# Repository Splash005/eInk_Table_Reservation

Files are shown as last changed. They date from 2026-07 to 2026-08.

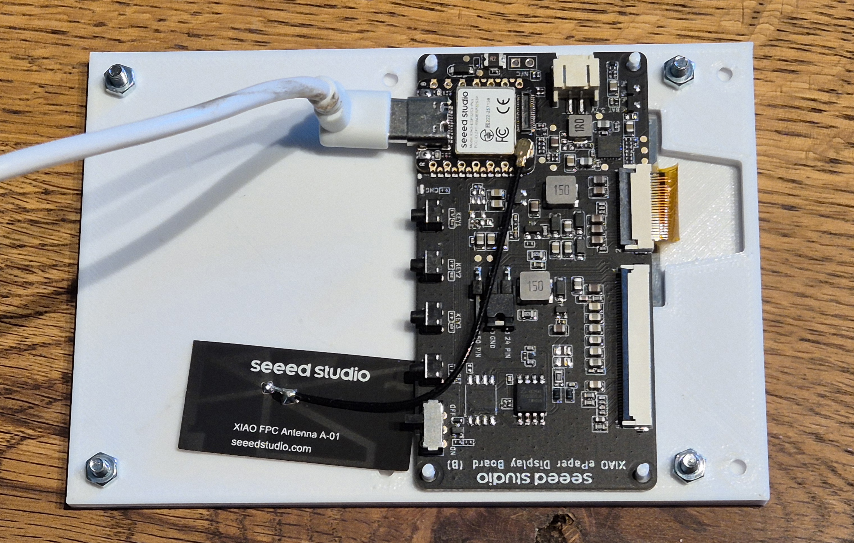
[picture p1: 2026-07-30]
pictures/Backside_with_PCB.jpg

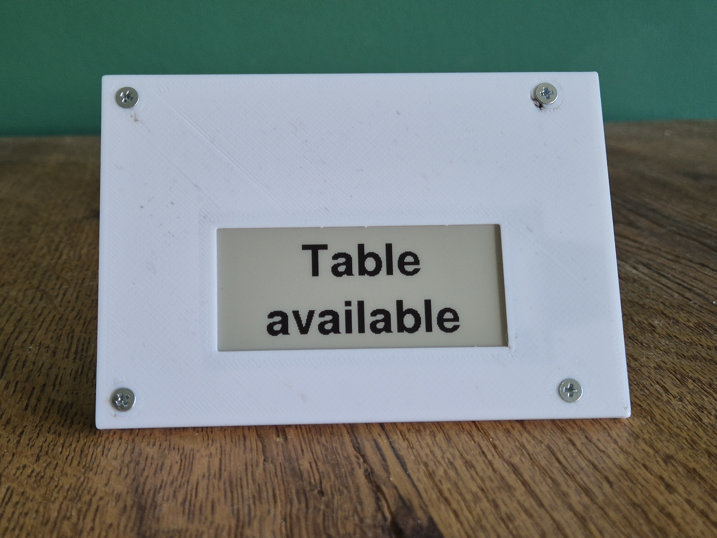
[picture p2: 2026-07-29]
pictures/Display_State_AVAILABLE.jpg

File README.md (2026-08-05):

# eInk_Table_Reservation
A Demo-Project for a smart Table-Reservation Sign, which has an integrated Webserver and handles reservations.  
It periodically checks the time and when the reservation is upcoming the screen changes to show customers that the table is reserved. When the reservation starts, it changes again its screen to welcome the customer and display a QR code with a link to the menu card.
The Wifi can be reconfigured over a webportal or reset with a physical button at the back of the board.
  
It is based on an ESP32 S3 and a 2,9 inch 4-color eInk Display. The driver board can be battery powered, but the software is currently designed to run on USB.

Video of the project:
https://youtu.be/43O6_xG3Szs

### Following products have been used:
- Driver Board --> XIAO ePaper Display Board(ESP32-S3) - EE04 (SKU 100075670)
- eInk Display --> 2.9" Quadruple Color eInk / ePaper Display with 128x296 Pixels, SPI interface, Support XIAO/Arduino (SKU 104990855)

| component | spezification / type |
| --- | --- |
| Microcontroller | ESeeed Studio XIAO ESP32S3 PLUS |
| Display | 2.9" E-Ink, 4-color (GDEY029F52) |
| Display-driver IC | JD79661 (resolution: 296 x 128 Pixel) |

## Used external libaries:
- **GxEPD2_4C** - for contolling the eInk display (custom integration designed from me for the above mentioned screen)
- **WiFiManager** - for the capitave Portal to configure the Wifi
- **QRCode** - custom integration for the generation of QR codes directly on the ESP
- **Standard ESP Libaries** - WiFi.h, WebServer.h, Preferences.h, time.h
  
## Pin wiring
| Function | ESP32 Pin | Description |
| --- | --- | --- |
| EPD_CS | D7 | Chip Select (SPI) |
| EPD_DC | 10 | Data/Command Control |
| EPD_RST | 38 | Reset Pin |
| EPD_BUSY | D3 | Busy-Signal of the display|
| SPI_SCK | D8 | SPI Clock |
| SPI_MOSI | D10 |SPI Master Out Slave In |
| SPI_MISO | 8 | SPI Master In Slave Out |
  
## State machine and display logic
| state | condition | display |
| --- | --- | --- |
| STATE_AVAILABLE | > 60 Min. before the starttime OR after endtime | big centered text: "Table available". |
| STATE_UPCOMING | less or exactly 60 minutes before the start time | yellow Warning background on the top. Text: "This table is reserved! From [Start] till [End] for: [Name]". Name in red. |
| STATE_ACTIVE | current time is between start and end time | "Welcome [Name]" (Name in red). QR-Code to the menu card. Endtime with yellow Font and outlined with black. |
  
## Logic Diagram
```
======================================================================
                         [ SETUP FUNCTION (setup) ]
======================================================================
                                   |
                                   v
             [ Init: Hardware, Display & load saved data ]
                                   |
                                   v
         +---------------- ( WiFi known? ) ------------------+
         |                                                   |
      [ Yes ]                                              [ No ]
         |                                                   |
         |                                                   v
         |                                [ start AP-Mode (Table_Reservation_AP) ]
         |                                [ display shows IP & QR-Code           ]
         |                                                   |
         |<--------------------------------------------------+ (After the setup from web portal)
         v
 [ get time (NTP)  ]
         |
 [ start webserver ]
         |
         v
======================================================================
                        [ MAIN FUNCTION (loop) ]
======================================================================
         |
         +
         |                                                       
         v                                                        
[ Check Web interfaces ] --> (New Data?) -> [ save and force Update]
         |                                                       
         v                                                       
[ Check Button ] ------> (3 Sec. pressed?) -> [ reset WiFi & Restart ]
         |                                                      
         v                                                       
( 10 seconds elapsed OR forced screen update? ) ------[ No ] -----+           
         |                                                        |
       [ Yes ]                                                    |
         |                                                        |
         v                                                        |
[ check time & State (updateDisplayLogik) ]                       |
         |                                                        |
         +---> (time < starttime AND > 60 Min) ---> [ AVAILABLE ] |
         +---> (time < starttime AND <= 60 Min) --> [ UPCOMING ]  |
         +---> (time >= starttime AND < endtime) -> [ ACTIVE ]    |
         +---> (time >= endtime) -----------------> [ AVAILABLE ] |
         |                                                        |
         v                                                        |
( state changed or display update is forced? ) -------[ No ] -----+  
         |                                                        |
       [ Yes ]                                                    |
         |                                                        |
         v                                                        |
[ update eInk display ]                                           |
         |                                                        |
[ set eInk in Hibernate mode ]                                    |
         |                                                        |
         +--------------------------------------------------------+
```
  
## Known Issues:
- currently the reservation is not deleted after it elapsed therefor it is still in memory and the table will be reserved the next day again.
  - Solution: After endtime elapsed delete reservation or create a flag if reservation has elapsed and check in the program for the flag. 

## Future Improvements:
- add an array of reservations and the ESP checks itself which reservation is next and after it elapsed delete it from the array
  - Advantages:
    - Multiple reservations can be entered for one table
        
- change the architecture from a webserver to a client which connects to a server and checks if reservations are available for this table (one server --> multiple Client architecture). The Reservation handling is done on the server and the client just checks it status and updates the display then goes to low power sleep.
  - Advantages:
    - Reservation handling is done on the server side (all reservations can be entered in one place with an table number and the clients check automatically if there is an upcoming reservation for their table number)
    - Client can be battery powered and goes to deepsleep until next check (currently no deepsleep for the ESP because it runs the webserver, the eink display is in sleep)

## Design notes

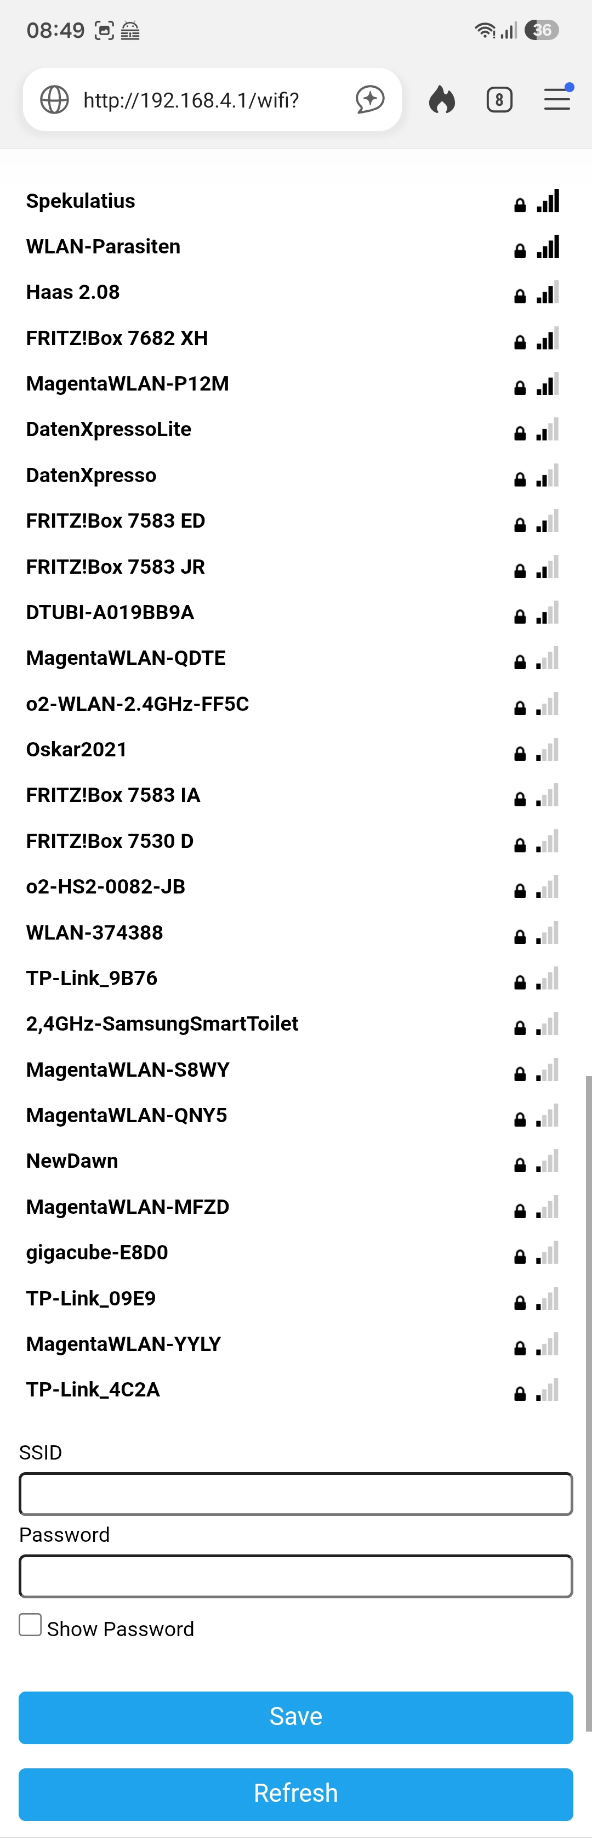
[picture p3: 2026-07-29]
pictures/Configure_WIFI_2.jpg

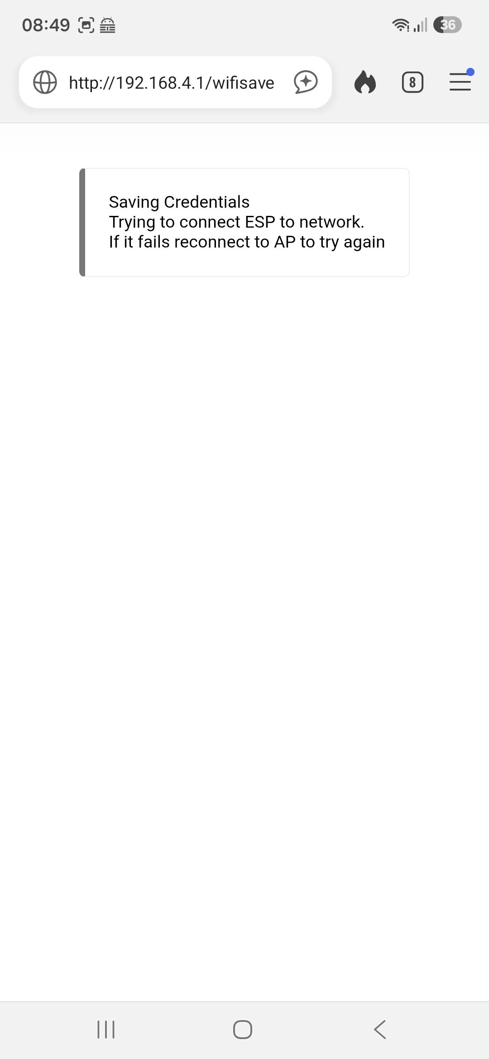
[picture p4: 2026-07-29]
pictures/Configure_WIFI_3.jpg

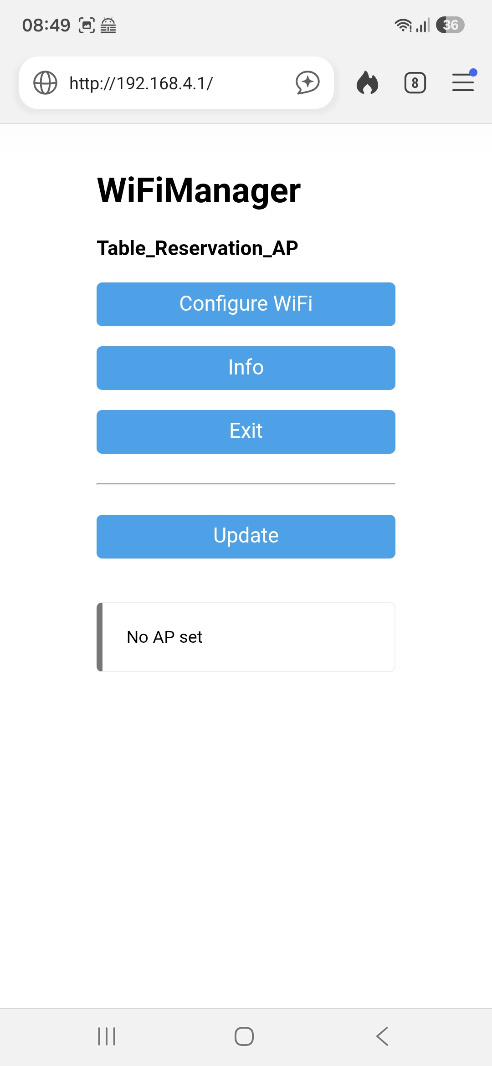
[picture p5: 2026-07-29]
pictures/Configure_WIFI_1.jpg

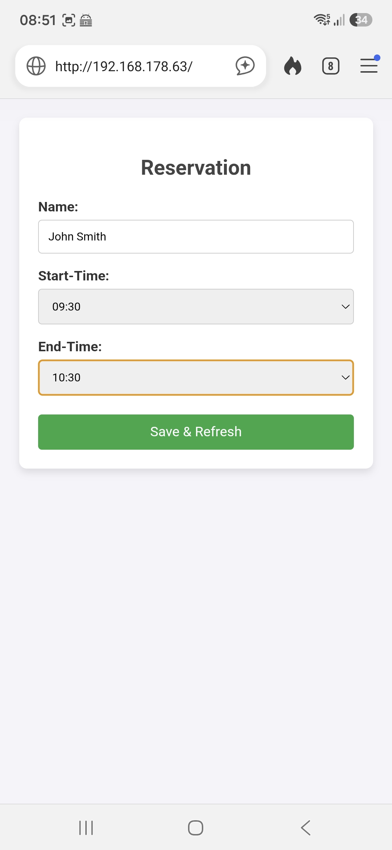
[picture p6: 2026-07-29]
pictures/Reservation_Website.jpg

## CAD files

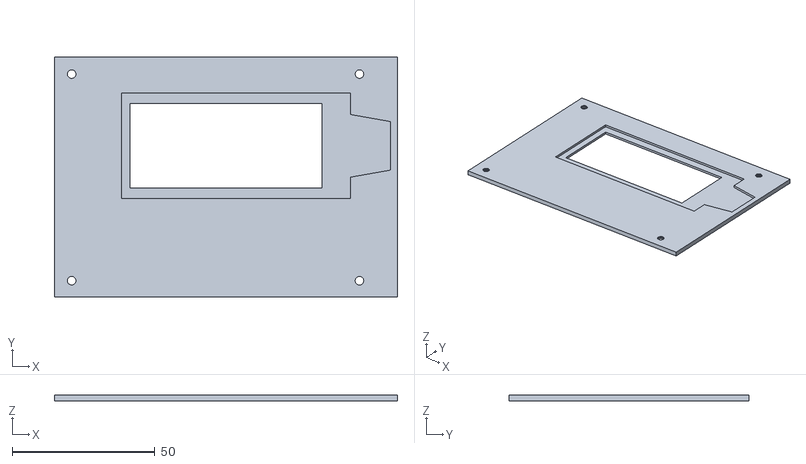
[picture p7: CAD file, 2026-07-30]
enclosure/Display_Holder.stl
120.0 x 84.0 x 2.00

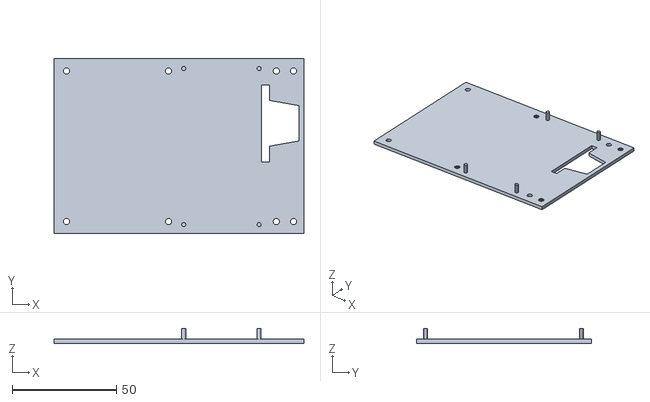
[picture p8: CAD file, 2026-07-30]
enclosure/BreakoutBoard_Holder.stl
120.0 x 84.0 x 7.00

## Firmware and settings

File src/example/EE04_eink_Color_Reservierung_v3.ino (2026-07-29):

/*
======================================================================
Interactive Table reservation Sign
======================================================================

This interactive table reservation sign should show the features of
an colored eink display. It is dynamically adjusting its content to
the time and status of the table.
The backend is currently a simple webserver where a name, start and
endtime can be configured, but in the future it can be modified to
be able to recieve data over mqtt or any other server-client connection.

This project was made for the "make a sign" competition of SeeedStudio.

Created by: S. Perrevoort
Date of last modification: 29.07.2026


********** Logic Diagram **********


======================================================================
                         [ SETUP FUNCTION (setup) ]
======================================================================
                                   |
                                   v
             [ Init: Hardware, Display & load saved data ]
                                   |
                                   v
         +---------------- ( WiFi known? ) ------------------+
         |                                                   |
      [ Yes ]                                              [ No ]
         |                                                   |
         |                                                   v
         |                                [ start AP-Mode (Table_Reservation_AP) ]
         |                                [ display shows IP & QR-Code           ]
         |                                                   |
         |<--------------------------------------------------+ (After the setup from web portal)
         v
 [ get time (NTP)  ]
         |
 [ start webserver ]
         |
         v
======================================================================
                        [ MAIN FUNCTION (loop) ]
======================================================================
         |
         +
         |                                                       
         v                                                        
[ Check Web interfaces ] --> (New Data?) -> [ save and force Update]
         |                                                       
         v                                                       
[ Check Button ] ------> (3 Sec. pressed?) -> [ reset WiFi & Restart ]
         |                                                      
         v                                                       
( 10 seconds elapsed OR forced screen update? ) ------[ No ] -----+           
         |                                                        |
       [ Yes ]                                                    |
         |                                                        |
         v                                                        |
[ check time & State (updateDisplayLogik) ]                       |
         |                                                        |
         +---> (time < starttime AND > 60 Min) ---> [ AVAILABLE ] |
         +---> (time < starttime AND <= 60 Min) --> [ UPCOMING ]  |
         +---> (time >= starttime AND < endtime) -> [ ACTIVE ]    |
         +---> (time >= endtime) -----------------> [ AVAILABLE ] |
         |                                                        |
         v                                                        |
( state changed or display update is forced? ) -------[ No ] -----+  
         |                                                        |
       [ Yes ]                                                    |
         |                                                        |
         v                                                        |
[ update eInk display ]                                           |
         |                                                        |
[ set eInk in Hibernate mode ]                                    |
         |                                                        |
         +--------------------------------------------------------+
*/

#include <WiFi.h>
#include <WiFiManager.h>
#include <WebServer.h>
#include <Preferences.h>
#include <time.h>
#include <qrcode_gen.h>

// --- E-Ink Display Setup (GxEPD2) ---
// JD79661 - GDEY029F52
// 296 width x 128 height

#include <GxEPD2_4C.h>
#include <Fonts/FreeSans9pt7b.h>
#include <Fonts/FreeSansBold9pt7b.h> // bold
#include <Fonts/FreeSans12pt7b.h>
#include <Fonts/FreeSansBold12pt7b.h> // bold
#include <Fonts/FreeSans18pt7b.h>
#include <Fonts/FreeSansBold18pt7b.h> // bold
#include <Fonts/FreeSans24pt7b.h>
#include <Fonts/FreeSansBold24pt7b.h> // bold

#define MAX_DISPLAY_BUFFER_SIZE 65536ul 
#define MAX_HEIGHT(EPD) (EPD::HEIGHT <= MAX_DISPLAY_BUFFER_SIZE / (EPD::WIDTH / 8) ? EPD::HEIGHT : MAX_DISPLAY_BUFFER_SIZE / (EPD::WIDTH / 8))

// Configuration Constants
const char* WIFI_AP_NAME = "Table_Reservation_AP";

// SPI Pins für ESP32-S3 (HSPI)
const int EPD_CS = D7;  
const int EPD_DC = 10;  
const int EPD_RST = 38;  
const int EPD_BUSY = D3;  
const int SPI_SCK = D8;  
const int SPI_MOSI = D10; 
const int SPI_MISO = 8;  

GxEPD2_4C<GxEPD2_290c_GDEY029F52, MAX_HEIGHT(GxEPD2_290c_GDEY029F52)> display(GxEPD2_290c_GDEY029F52(/*CS=*/ EPD_CS, /*DC=*/ EPD_DC, /*RST=*/ EPD_RST, /*BUSY=*/ EPD_BUSY));

// --- Pushbutton Pins ---
const int BTN_WAKE_1 = 2; // to be defined
const int BTN_WAKE_2 = 3; // to be defined
const int BTN_CONFIG = 5; // reset WiFi

// --- Webserver ---
WebServer server(80);

// --- variables & memory ---
Preferences preferences;
String resName = "John Doe";
String startTime = "18:00";
String endTime = "20:00";

const char* ntpServer = "pool.ntp.org";
const char* tzInfo = "CET-1CEST,M3.5.0,M10.5.0/3"; 

// --- state machine for the display ---
enum DisplayState { STATE_UNKNOWN, STATE_AVAILABLE, STATE_UPCOMING, STATE_ACTIVE };
DisplayState currentDisplayState = STATE_UNKNOWN;
bool forceDisplayUpdate = true; // force update at the beginning

unsigned long lastTimeCheck = 0;
const unsigned long timeCheckInterval = 10000; // check every 10 seconds

// --- HELPER functions ---
int getMinutesFromMidnight(String timeStr) {
  int h, m;
  if (sscanf(timeStr.c_str(), "%d:%d", &h, &m) == 2) {
    return h * 60 + m;
  }
  return 0;
}

void drawCenteredText(const String& text, int yPos) {
  // 1. variables for the textrecognition
  int16_t tbx, tby;
  uint16_t tbw, tbh;

  // 2. Calculate Textboundaries
  display.getTextBounds(text, 0, 0, &tbx, &tby, &tbw, &tbh);

  // 3. calculate X-coordinate for the middle of the screen
  int centerX = (display.width() - tbw) / 2 - tbx;

  // 4. draw text
  display.setCursor(centerX, yPos);
  display.print(text);
}

void drawOutlinedText(String text, int x, int y, uint16_t fillingcolor) {
  // 1. Draw BLACK text with an offset
  display.setTextColor(GxEPD_BLACK);
  
  display.setCursor(x - 1, y); display.print(text);
  display.setCursor(x + 1, y); display.print(text);
  display.setCursor(x, y - 1); display.print(text); 
  display.setCursor(x, y + 1); display.print(text);
  
  // Optional: diagonal offset for a smoother transition
  display.setCursor(x - 1, y - 1); display.print(text);
  display.setCursor(x + 1, y - 1); display.print(text);
  display.setCursor(x - 1, y + 1); display.print(text);
  display.setCursor(x + 1, y + 1); display.print(text);

  // 2. Fill in the Text in the middle in the defined color
  display.setTextColor(fillingcolor);
  display.setCursor(x, y);
  display.print(text);
}

void drawQRCode(const char* url, int offsetX, int offsetY, int scale) {
  QRCode qrcode;
  uint8_t qrcodeData[qrcode_getBufferSize(3)];
  qrcode_initText(&qrcode, qrcodeData, 3, 0, url);

  for (uint8_t y = 0; y < qrcode.size; y++) {
    for (uint8_t x = 0; x < qrcode.size; x++) {
      if (qrcode_getModule(&qrcode, x, y)) {
        display.fillRect(offsetX + (x * scale), offsetY + (y * scale), scale, scale, GxEPD_BLACK);
      }
    }
  }
}

// --- HTML for the webinterface ---
const char* htmlForm = R"rawliteral(
<!DOCTYPE html>
<html>
<head>
  <meta charset="UTF-8">
  <meta name="viewport" content="width=device-width, initial-scale=1.0">
  <title>Table-Reservation</title>
  <style>
    body { font-family: Arial, sans-serif; margin: 20px; background-color: #f4f4f9; color: #333; }
    .container { max-width: 400px; margin: auto; background: white; padding: 20px; border-radius: 8px; box-shadow: 0 4px 8px rgba(0,0,0,0.1); }
    h2 { text-align: center; color: #444; }
    label { font-weight: bold; display: block; margin-top: 15px; }
    input[type="text"], input[type="time"] { width: 100%; padding: 10px; margin-top: 5px; border: 1px solid #ccc; border-radius: 4px; box-sizing: border-box; }
    input[type="submit"] { width: 100%; padding: 10px; margin-top: 20px; background-color: #28a745; color: white; border: none; border-radius: 4px; cursor: pointer; font-size: 16px; }
    input[type="submit"]:hover { background-color: #218838; }
  </style>
</head>
<body>
  <div class="container">
    <h2>Reservation</h2>
    <form action="/save" method="POST">
      <label>Name:</label>
      <input type="text" name="name" value="%NAME%" maxlength="40" required>
      <label>Start-Time:</label>
      <input type="time" name="start" value="%START%" required>
      <label>End-Time:</label>
      <input type="time" name="end" value="%END%" required>
      <input type="submit" value="Save & Refresh">
    </form>
  </div>
</body>
</html>
)rawliteral";

void handleRoot() {
  String page = htmlForm;
  page.replace("%NAME%", resName);
  page.replace("%START%", startTime);
  page.replace("%END%", endTime);
  server.send(200, "text/html", page);
}

void handleSave() {
  if (server.hasArg("name")) resName = server.arg("name");
  if (server.hasArg("start")) startTime = server.arg("start");
  if (server.hasArg("end")) endTime = server.arg("end");

  // Save in Preferences
  preferences.begin("reservations", false);
  preferences.putString("name", resName);
  preferences.putString("start", startTime);
  preferences.putString("end", endTime);
  preferences.end();

  // force the display to be updated, because the data has been refreshed
  forceDisplayUpdate = true; 
  
  // send back to main-page
  server.sendHeader("Location", "/");
  server.send(303);
}



/*
======================================================================
                         [ SYSTEMSTART (ESP32) ]
======================================================================
*/

void setup() {
  Serial.begin(115200);
  
  pinMode(BTN_WAKE_1, INPUT_PULLUP);
  pinMode(BTN_WAKE_2, INPUT_PULLUP);
  pinMode(BTN_CONFIG, INPUT_PULLUP);

  // 1. Load memory
  preferences.begin("reservations", false);
  resName = preferences.getString("name", resName);
  startTime = preferences.getString("start", startTime);
  endTime = preferences.getString("end", endTime);
  preferences.end();

  // 2. initialize display
  SPI.begin(SPI_SCK, SPI_MISO, SPI_MOSI, EPD_CS);
  display.init(115200);
  display.setRotation(1);

  // 3. WLAN configuration
  WiFiManager wm;
  
  // If GPIO 5 is pressed at start, reset WLAN configuration and start AP
  if (digitalRead(BTN_CONFIG) == LOW) {
    Serial.println("GPIO 5 pressed: Reset WLAN!");
    wm.resetSettings();
  }

  // A Callback (eine Funktion) for the WiFiManager to check if it is in AP-Mode:
  wm.setAPCallback([](WiFiManager *myWiFiManager) {
    Serial.println("AP-Mode started - Update Display...");
    
    // Init Display and show AP informations
    display.setFullWindow();
    display.firstPage();
    do {
      display.fillScreen(GxEPD_WHITE);
      
      display.setFont(&FreeSansBold9pt7b);
      display.setTextColor(GxEPD_BLACK);
      display.setCursor(10, 30);
      display.print("Connect to:");

      display.setFont(&FreeSans12pt7b);
      display.setCursor(10, 60);
      display.print(WIFI_AP_NAME);

      display.setFont(&FreeSansBold9pt7b);
      display.setCursor(10, 90);
      display.print("IP: ");
      
      display.setFont(&FreeSans12pt7b);
      display.setTextColor(GxEPD_RED);
      display.setCursor(10, 120);
      display.print("192.168.4.1");

      String qrText = String("WIFI:T:nopass;S:") + WIFI_AP_NAME + ";;";
      drawQRCode(qrText.c_str(), 230, 70, 2);

    } while (display.nextPage());
    display.hibernate();
  });

  // connects automatically or starts AP-Mode
  if (!wm.autoConnect(WIFI_AP_NAME)) {
    Serial.println("WLAN connection failed. Restart.");
    ESP.restart();
  }

  Serial.print("WLAN connected. Web-Interface can be reached unter: http://");
  Serial.println(WiFi.localIP());

  // get current time
  configTzTime(tzInfo, ntpServer);

  // 4. start Webserver 
  server.on("/", HTTP_GET, handleRoot);
  server.on("/save", HTTP_POST, handleSave);
  server.begin();
}




/*
======================================================================
                        [ HAUPTSCHLEIFE (loop) ]
======================================================================
*/

void loop() {
  // handle Webserver requests
  server.handleClient();

  // WLAN Reset while in run (Button 3 Seconds pressed)
  if (digitalRead(BTN_CONFIG) == LOW) {
    delay(3000); 
    if (digitalRead(BTN_CONFIG) == LOW) {
      Serial.println("WLAN Reset through button. Restart...");
      WiFiManager wm;
      wm.resetSettings();
      ESP.restart();
    }
  }

  // Check every 10 seconds if status is changed
  if (millis() - lastTimeCheck > timeCheckInterval || forceDisplayUpdate) {
    lastTimeCheck = millis();
    updateDisplayLogik();
  }
}

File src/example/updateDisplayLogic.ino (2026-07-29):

void updateDisplayLogik() {
  struct tm timeinfo;
  if (!getLocalTime(&timeinfo)) {
    return; // return if no time is available
  }

  int currentMinutes = timeinfo.tm_hour * 60 + timeinfo.tm_min;
  int startMinutes = getMinutesFromMidnight(startTime);
  int endMinutes = getMinutesFromMidnight(endTime);

  // calculate the minutes to start time in minutes
  int minutesUntilStart = startMinutes - currentMinutes;

  DisplayState newState;

  if (currentMinutes < startMinutes && minutesUntilStart <= 60) {
    newState = STATE_UPCOMING;
  } else if (currentMinutes >= startMinutes && currentMinutes < endMinutes) {
    newState = STATE_ACTIVE;
  } else {
    newState = STATE_AVAILABLE;
  }

  // ONLY refresh the display if the state is changed
  // OR the forceDisplayUpdate is requested (webinterface changed data)

  if (newState != currentDisplayState || forceDisplayUpdate) {
    Serial.println("Display updating...");
    
    //display.setFullWindow();
    display.setPartialWindow(0, 0, display.width(), display.height());
    display.firstPage();

    display.fillScreen(GxEPD_WHITE);
    
    do {

      if (newState == STATE_UPCOMING) {
        display.fillRect(0, 0, 296, 40, GxEPD_YELLOW);
        display.fillRect(0, 40, 296, 2, GxEPD_BLACK);

        display.setFont(&FreeSansBold12pt7b);
        display.setTextColor(GxEPD_BLACK);
        display.setCursor(6, 30);
        display.print("This table is reserved !");

        display.setFont(&FreeSans12pt7b);
        display.setCursor(6, 70);
        display.print("From ");
        display.print(startTime);
        display.print(" till ");
        display.print(endTime);
        display.print(" for:");
      
        display.setFont(&FreeSansBold12pt7b);
        display.setCursor(26, 105);
        display.setTextColor(GxEPD_RED);
        //drawCenteredText(resName, 105);     
        display.print(resName);

     } else if (newState == STATE_ACTIVE) {
        display.setFont(&FreeSansBold18pt7b);
        display.setTextColor(GxEPD_BLACK);
        display.setCursor(6, 35);
        display.print("Welcome");
      
        display.setFont(&FreeSansBold12pt7b);
        display.setTextColor(GxEPD_RED);
        display.setCursor(6, 65);
        display.print(resName);
      
        display.setTextColor(GxEPD_BLACK);
        display.setFont(&FreeSansBold9pt7b);
        display.setCursor(6, 120);
        display.print("Your table is reserved till:");
        drawOutlinedText(endTime, 230, 120, GxEPD_YELLOW);

        drawQRCode("https://your-restaurant.com/Food-Menu", 200, 6, 3); //90x90 Pixel

      } else if (newState == STATE_AVAILABLE) {
        display.setFont(&FreeSansBold24pt7b);
        display.setTextColor(GxEPD_BLACK);
        drawCenteredText("Table", 50);
        drawCenteredText("available", 110);
      }
    } while (display.nextPage());
    display.hibernate();

    currentDisplayState = newState;
    forceDisplayUpdate = false;
  }
}
